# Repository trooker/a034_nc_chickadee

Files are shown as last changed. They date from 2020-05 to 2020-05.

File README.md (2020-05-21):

# a034_nc_chickadee
Ventilator Simulator Platform Synthesized From Published Mechanical Ventilator Design Literature Via FreeCAD Opensource CNC Machine Technology Using Arduino Boards/Shields

See: http://abbottanp.com/ for project engineering details.

While stuck in "lock-down" this project evolved and matured.  

Disclaimer:

1> The project presented here as a lowcost Ventilator Simulator Platform. It is not a qualified medical device at any level. This projects as presented here is not qualifed for any medical application. The project as presented should serve as a test platform and simulator supporting further development of the bio-medical equipment.

2> No warranty is made regarding the servicability or fitness for use of this low cost prototype ventilator. A user may employ, enjoy or engage in this project under the terms of the GNU General Public License (GNU GPL or GPL) as OpenSource software licenses that guarantee end users the freedom to run, study, share, and modify the software. All copyrights privildeges are reserved.

Evolution of Project:

The goal of this project was to gain a layman's level of understanding of the complexity of ventilators. This understanding was to be added to my CommonPlace Book of knowledge. While chasing this pursuit various seacrh strings associated with Forrest Bird led to the referensnces listed further below. The question eventually became one of "can CNC style machines possibly accomplish some level of ventilator fucntionality" using only components currently "on-hand"? Once that has been achieved can the resulting venitlator simulation platform serve a useful purpose as a learnig resource?
Working Assumptions:

Working Assumptions:

    +Ability to read technical material and translate into specification/work-product.
    +Experience creating Arduino project content within Sloeber or similar IDE.
    +Facility to adapt hardware as need to integrate with software to accomplish a task.
    +Implementing a design using only parts that are currently in the project's einventory.

Reference:

++ MIT Student Project: https://web.mit.edu/2.75/projects/DMD_2010_Al_Husseini.pdf

++ Theory of Operation: https://my.clevelandclinic.org/-/scassets/files/org/respiratory/fundamentals-of-mechanical-ventilation.ashx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

++ Excellent Introduction Class: https://www.k-space.org/Class_Info/EE497/KAU_Ventilator_lec.pdf

Status:

1> Project completed to the point where additonal components would need to be purchased and incorporated.  The Arduino program module is functional at the Arduino Base Shield and Stack.  The program drives an X axis piston stepper and two angular motion  AB axes to control inspiration and expiration.  The most minimal breaths per minute for the Tidal Volume (expressed as mL) was demonstrated by the "model".  No air flow was achieved due to the lack of components. 

2> Using FreeCAD the mechanical aspects of the ventilator simulatior prototype platform was generated.  That lead to several evolutions in the approach ot the toolpaths needed for generting a gcode set of statements for integrating a "piston stroke cycle coupled with inspiration and expiration valve control. The proposed gcode soultion was verified at tthe Arduino stack level and under LinuxCNC.  

3> A routine process of converting a test subjects ventilation requirements into the volume and piston stroke length was achieved.  A basic web page input form collects the specification.  That is emailed to a receipent who makes a global repalcement (from "=" to ",") in the specification/data.  That data is then imported to a "canned" spreadsheet that parse the data elements into usable "gcode" content.  Loading that content to a file called "dilni.ngc" allows the "ventilator simulator" to executed cleanly.

4> It served as a great learning tool.

Closing:

Helpful comments are encouraged.  The spelling, grammar, and syntax will improve if the project moves forward from this point.

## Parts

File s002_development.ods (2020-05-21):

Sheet: Development Only
 |  | Given | Calculate |  |  |  | PVC Pipe | PVC Dia IO | Radius | h for Vtt | Cycle Time 1706.7 Steps/Inch | Cycle Time 46.4 Steps/Inch | PVC Pipe 1.5 | Cycle Time 46.4 Steps/Inch | Body Weight Pounds | Tidal Volume VT kg/ml
 | Pounds to Kilograms | 1 | 0.453592 | 0.453592 |  |  | 0.75 | 0.769 | 0.3845 | 17.9 |  |  | 10.0
 |  | 150 | 68.0 |  |  |  | 1 | 1.029 | 0.5145 | 10.0 |  |  | 10.0
 | CubicInch to MiliLiters | 1 | 16.3871 | 16.3871 |  |  | 1.5 | 1.61 | 0.805 | 4.1 | 01:35 | 39.9 | 10.0 |  |  | 2
 |  | 8 | 131.097 |  |  |  | 2 | 2.03 | 1.015 | 2.6 | 01:14 |  | 10.0
 |  |  |  |  |  |  | 2.5 | 2.61 | 1.305 | 1.6 | 01:00 |  | 10.0
 |  |  |  |  |  |  | 3 | 3.03 | 1.515 | 1.2 | 00:55 |  | 10.0
 |  |  |  |  |  |  | 3.5 | 3.6 | 1.8 | 0.8 | 00:50 |  | 10.0
 | pulled from email ==> | Inputs4venti_999 |  |  |  |  | 4 | 4.03 | 2.015 | 0.7 | 00:48 |  | 10.0
From doEmail.html |  | inputs4venti_998.csv |  |  |  |  | 4.5 | 4.6 | 2.3 | 0.5 | 00:45 |  | 10.0
email |  | Pasted as CSV |  |  | Calculation | Copy to Header of dilni.ngc | 5
aname=afgxn nsh | Author’s Name | aname | afgxn nsh |  | afgxn nsh | ;Author: afgxn nsh
amail=nowat@here.com | Author’s Email | amail | nowat@here.com |  | nowat@here.com | ;Author-Email: nowat@here.com
aphone=392-984-9903 | Author’sTelephone | aphone | 392-984-9903 |  | 392-984-9903 | ;Author-Telephone: 392-984-9903
sname=klhhl jupo | Subject’s Name | sname | klhhl jupo |  | klhhl jupo | ;Subject: klhhl jupo
eweight=150 | Weight LBS | eweight | 150 |  |  | ;NOTE: Hello cowboy
mweight= | Weight KG | mweight |  |  | 68.0 | ;Weight kg: 68.0388
stvolume=2 | Tidal Volume mL/kg | stvolume | 2 |  | 136.1 | ;Tidal Volume mL==: 136.0776
comment=Hello cowboy. | Comment: Yes/No | comment | Hello cowboy |  | no
 |  |  |  |  |  | G1 X-4.07889854937866 |  | Vtt In^3
 |  |  |  |  |  |  |  | 8.3039463969

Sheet: Input_Worksheet
 | Given | Calculate
Pounds to Kilograms | 1 | 0.453592
 | 150 | 68.0
CubicInch to MiliLiters | 1 | 16.3871
 | 8 | 131.097
Data pulled from email | Inputs4venti_iii.csv |  |  | 1> Copy data from email to a text file.
From doEmail.html | inputs4venti_998.csv | Example |  | 2> Perform a global replacement of “=” with “,”
Data As Received | aname=afgxn nsh | Name “=” Value |  | 3> Save text file with csv extension.
 |  |  |  | 4> Import csv text file to C13. |  |  |  |  |  |  |  | 150 Pound Body Weight
 |  |  |  |  |  |  |  |  |  |  |  | PVC Pipe 1.5 |  |  | PVC Pipe 1.0 |  |  | PVC Pipe 2.0
Content of Input Email As Received Prior to Converting to CSV | Comment | Object’s Name | Object’s Value |  | Calculation |  | Copy to Header of “dilni.ngc” | PVC Pipe | PVC Dia Interior Inch | Radius | Length of Required Stroke | Tidal Volume ML/kg | Length of Required Stroke |  | Tidal Volume ML/kg | Length of Required Stroke |  | Tidal Volume ML/kg | Length of Required Stroke
aname=afgxn nsh | Author’s Name | aname | afgxn nsh |  | afgxn nsh |  | ;Author: afgxn nsh | 1 | 1.029 | 0.5145 | 10.0 | 2 | 4.1 | * | 2 | 10.0 | ** | 2 | 2.6
amail=nowat@here.com | Author’s Email | amail | nowat@here.com |  | nowat@here.com |  | ;Author-Email: nowat@here.com | 1.5 | 1.61 | 0.805 | 4.1 | 4 | 8.2
aphone=392-984-9903 | Author’s Telephone | aphone | 392-984-9903 |  | 392-984-9903 |  | ;Author-Telephone: 392-984-9903 | 2 | 2.03 | 1.015 | 2.6 | 6 | 12.2
sname=klhhl jupo | Subject’s Name | sname | klhhl jupo |  | klhhl jupo |  | ;Subject: klhhl jupo |  |  |  |  | 8 | 16.3
eweight=150 | Weight LBS | eweight | 150 | lbs |  | na | ;NOTE: Hello cowboy |  |  |  |  | 10 | 20.4 | ** | 10 | 49.9 |  | 10 | 12.8
mweight= | Weight KG | mweight |  | kg | 68.0 | kg | ;Weight kg: 68.0388 |  |  |  |  | 20 | 40.8
stvolume=2 | Tidal Volume mL/kg | stvolume | 2 | mL/kg | 136.1 | mL | ;Tidal Volume mL==: 136.0776 |  |  |  |  | 50 | 102.0
comment=Hello cowboy. | Comment: Yes/No | comment | Hello cowboy |  | no |  |  | Vtt In^3
 |  |  |  |  |  |  | G1 X-4.07889854937866 | 8.3039463969 |  |  |  |  |  |  |  |  | *: 39.9 seconds as tested 200514_1307
 |  |  |  |  |  |  |  |  |  |  |  |  |  |  |  |  | **: 21.8 start + cycle, 16.2 cycle
 |  |  |  |  |  |  |  |  |  |  |  |  |  |  |  |  | ***: Material on-hand.

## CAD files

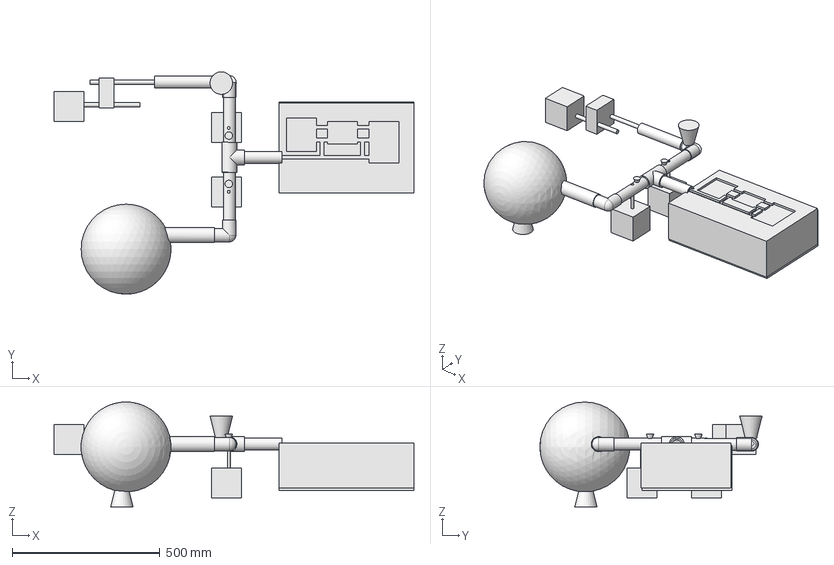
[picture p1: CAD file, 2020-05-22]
037_972_nc_chickadee_3stepper_working.FCStd
1219.2 x 753.0 x 355.1 mm
block
Inspiration001
Exspiration001
Elbow_Cut_Esp
Elbow_Cut_Insp
Vortex
Exspiration
Inspiration
TeeCoupler
ExhaustReservoir+Bleeder
Saddle1
Leadscrew
Stepper1
Piston
Stepper2
ExpPressureCone
InspPressureCone
InspInletValve
Stepper3

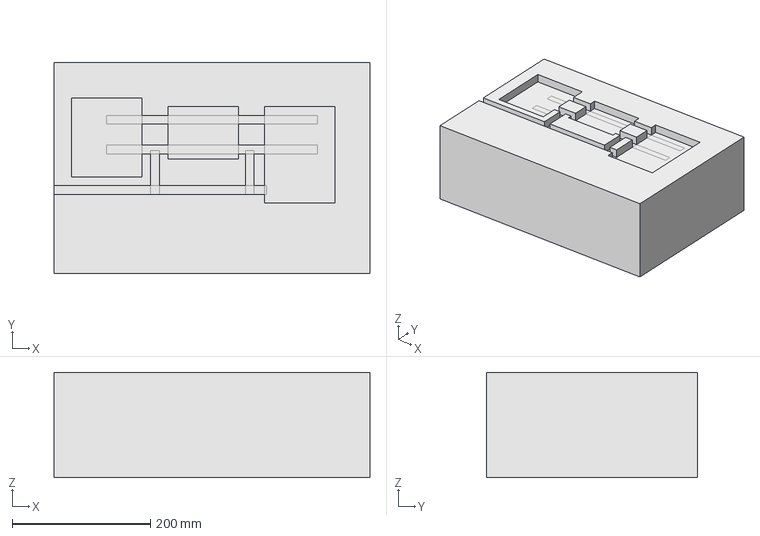
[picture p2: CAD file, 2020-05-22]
036_testLungRespitoryProfile_987.FCStd
457.2 x 304.8 x 152.4 mm

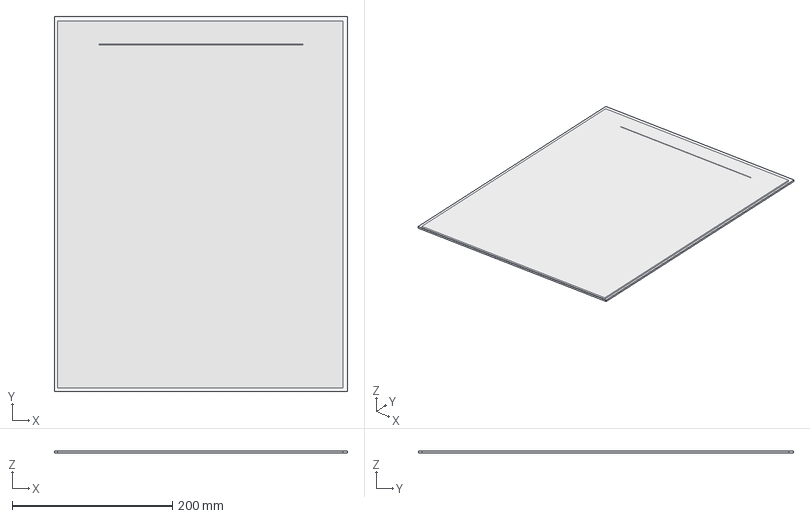
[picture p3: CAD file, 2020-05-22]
037_985_chickadee.FCStd
365.8 x 467.4 x 2.54 mm
WorkPlate_PistonCut
Model-WorkPlate_PistonCut
Model-WorkPlate
Stock

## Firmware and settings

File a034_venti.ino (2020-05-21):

/* Copyright © 1988-2020 by Abbott Analytical Products. All Rights Reserved.
 * 200427_tr seems ot have broken the SD read looping
 *        Everything now hangs at the LCD setup fina 1403 message
 * 200426_tr removed showDisplay stuff
 * 200423_tr upgrade the angular movemnt of stepper A/B ref:
 *        http://linuxcnc.org/docs/html/gcode/g-code.html#gcode:g93-g94-g95
 *        using the lure flipper as a template:
 *        G1 G93 G53 A180.00000 F2
 *        Could also use the G94.  Need to test later.
 *        Physically hooked the Stepper B to AMStop. Still have questions about
 *        stepper A/B pin defs in config.h
 *        Evaluating the use of forcing one instruction per line instead of the
 *        normal gcode string of instructions.
 * 200421_tr have FreeCAD and oxxx subroutines workign at Linuxcnc level for testing
 *        of model.
 *        Need G93, G53, A abd B steppers, o101, o102, o103 hard coded into ngc.
 *        angular movement instead of linear.
 *        need to remove extraneous linear tool movement.  Only th e XY are linear
 * 200405_tr copied from a021_xystepper
 *        verified the upload went well.  Setup Fina 2132 confirmed.
 *        confirmed xy both work working with the shields
 *        SD reading functions.  LED and LCD ok. use dilni.ngc in config.h
 *        for test filename.
 *      ##Discovered a potential issue with SD reading and interrupts causing the
 *        targetFileName to become corrupted.  Need Alarm.
 *
 *
 * 200405_tr_ renamed to suit project from: a021_xystepper_gCodeParser_012.ino
 * 180804_tr started adding a axis, I and J for g02/g03 arch moves.
 * 170421_tr completed rebuild using hte Sloeber  G1 X230 Y300 runs.
 *     G1 X422 Y70 runs steppers
 * 170420 Trying to conver to Sloeber
 *     There is a problem with the input 170420_xy... or output to the log
 * 170419 GtkTerm (ASCII tty_ACM0) 170419_usc18 hangs and awaits firing of
 *        gcode file
 * 170418 GtkTerm and 170418_usc018_eject_logadj.cnc no longer works
 *        Note 170419_*.cnc was built from 170416_log_2158.
 * 170415 Cleanup serial prints and leverge feedrate
 *    Serial Monitor
 *    170414_usc018_eject.cnc line by line
 *    G1 X51.668 Y72.274 F7800.000 => RUns Y okay
 *
 * 170413_work with feedrate, absolute/incremental and units of measure
 *         F, G90/G91, G20/G21
 *         G90;G20; G1 X300 Y100 turns every thing
 *         Corrected for _STEPS_PER_IN/MM
 *         G90; G20; G1 X460 Y10
 * 170411 Added Working on FeedRate
 * 170410 Both XY work to some level via Serial Monitor
 *        G0 X230 Y50
 *        G0 X300 Y5
 *        G0 X-330 Y4
 *          Yeilds
 *          errAdj += difY 275..298
 *                         299, 300
 *             Called backward1()
 *        G0 X500 Y2
 *          errAdj += difY 370, 372,by 2's 400
 *             Called forward1()
 *        G1 X199 Y0
 *        G1 X-195 Y3
 *        Read 002.2_testLine_repeat.cnc from GtkTerm
 *          But no stepper motion
 *        Read boomerangv4_03.cnc from GtkTerm
 *          But no stepper motion
 * 170409 looking at line() function of parse_cmdln
 * 170402_merge GCodeCNCDemo2 with Adafruit Motor shield
 *     drop extraneous controllers
 *     works with G00 code from Serial Monitor command line.
 *   1> Used GtkTerm and boomeragn.cnc to drive steppers
 *   2> GtkTerm copy/paste of r004_002_testLine runlog to drive
 *   3> raw file GtkTerm + 002_testLine_repeast.nc
 *   4> raw file GtkTerm ...
 *
 *
 *
 * 170330
 *
 * https://github.com/MarginallyClever/GcodeCNCDemo/wiki
 * https://github.com/MarginallyClever/GcodeSender
 */


#include "a034_config.h"

//------------------------------------------------------------------------------
// GLOBALS
//------------------------------------------------------------------------------

//int   sofar;            // how much is in the buffer
int copyMax = 1;
int copyKnt = 0;



// settings

//From GCodeParser
//#define COMMAND_SIZE 128
char commands[COMMAND_SIZE];
byte serial_count;
int no_serialData = 0;        // attempts to read Serial port
bool comment = false;



//------------------------------------------------------------------------------
// METHODS
//------------------------------------------------------------------------------


//170701_tr
rgb_lcd lcd;

int cnt = 0;
const int LED    = 2;       // the Grove port No. you attached an LED to


String readString = "";
int ledState = LOW;             // ledState used to set the LED
long previousMillis = 0;        // will store last time LED was updated
// the follow variables is a long because the time, measured in miliseconds,
// will quickly become a bigger number than can be stored in an int.
long interval = 1000;           // interval at which to blink (milliseconds)
int doneFlag = -1;              // think tristate
int kntr = 0;                   // loop counter
int loopknt = 0;         // count loop cycles
bool loopdebug = true;  //false;   // controls serial printing of debug info:  true is doit
int workknt = 0;         // count cycle through work
int wait4loop = 10000;
int endOn = wait4loop;         // 200;         // end work loop after
int closeLoopOn = wait4loop;   // end arduino looping after 200 cycles
// Define the delay for the "breathing" effect; change this
// to a smaller value for a faster effect, larger for slower.
const int BREATH_DELAY = 5; // milliseconds



int buzz1Knt = 1;        //
int buzz2Knt = 1;        //
int buzz3Knt = 1;        //siren
int buzzOff  = 2;

const int sigId_led    = 3;     //Port 3 LED   OUTPUT
const int sigId_btn    = 6;     //Port 7 btn   INPUT
const int sigId_buz    = 5;     //Port 6 buzzer OUTPUT


/*
 * wrting a string for trouble shooting loop issues
 */

void loopPrn(String msg)
{
	if (loopdebug == true)
	{
		Serial.println(msg);
	}
}



/**
 * write a string followed by a float to the serial line.  Convenient for debugging.
 * @input code the string.
 * @input val the float.
 */
void foutput(const char *code,float val)
{
 if (isReadyFlag == true)
 {
  Serial.print(code);
  Serial.print(".....");  // my test ln
  Serial.println(val,4);
 }
}


/**
 * print the current position, feedrate, and absolute mode.
 */
void where()
{
  foutput("popped from where() of venit.ino", BADNbr);
  foutput("kntX",kntX);
  foutput("kntY",kntY);
  foutput("Distance along X Axis",kntX / x_steps2in );
  foutput("Distance along Y Axis",kntY / y_steps2in);
  foutput("x units", x_steps2in);
  foutput("y units", y_steps2in);
  foutput("a units", a_steps2deg);
  foutput("b units", b_steps2deg);
  foutput("Current_LocX",current_loc.x);
  foutput("Current_LocY",current_loc.y);
  foutput("Current_LocA",current_loc.a);
  foutput("Current_LocB",current_loc.b);


  foutput("Last fp.X requested via gCode ",fp.x);
  foutput("Last fp.Y requested via gCode ",fp.y);
  foutput("Last fp.a requested via gCode ",fp.a);
  foutput("Last fp.b requested via gCode ",fp.b);

  foutput("F",feedrate);
  foutput("E", extrude);
  foutput("abs_mode ",abs_mode);
}

void help()
{
	//Serial.println("Need help with Flash memory F thingie");
	  Serial.print(F("GcodeCNCDemo2AxisV1 Help: "));
	  Serial.println(VERSION);
	  Serial.println(F("Unit of Measure is in Inches for Linear and Degrees for Angular"));
	  Serial.println(F("Commands:  Used by dilningc"));
	  Serial.println(F("G00 [X(steps)] [Y(steps)] [E(extrude)] [F(feedrate)]; ==> Linear"));
	  Serial.println(F("G01 [X(steps)] [Y(steps)]  [E(extrude)] [F(feedrate)]; ==> Linear"));
	  Serial.println(F("G01 G93 G53 [A(degs)]  [B(degs)][F(feedrate)]; ==> Angular"));
	  Serial.println(F("G20 Set units to inches"));
	  Serial.println(F("G04 P[seconds]; ==> delay"));
	  Serial.println(F("G90; absolute mode"));
	  Serial.println(F("G93; Angular movement of StepperA/B"));
	  Serial.println(F("G53; Machine Coordinate System. Ignored"));
	  Serial.println(F("M02; End of Program"));
	  Serial.println(F("M18; - disable motors"));
	  Serial.println(F("M100; - this help message"));
	  Serial.println(F("M114; - report position and feedrate"));
	  Serial.println(F("All commands must end with a newline."));

//	  Serial.println(F("-G02 [X(steps)] [Y(steps)] [I(steps)] [J(steps)] [E(extrude)] [F(feedrate)]; ==> clockwise arc"));
//	  Serial.println(F("-G03 [X(steps)] [Y(steps)] [I(steps)] [J(steps)] [E(extrude)] [F(feedrate)]; ==> counter-clockwise arc"));
//	  Serial.println(F("-G21 Set units to mm"));
//	  Serial.println(F("-G91; - relative mode"));
//	  Serial.println(F("-G92 [X(steps)] [Y(steps)]; - change logical position"));
//	  Serial.println(F("-M05; - Stop spindle"));

}


/**
 * prepares the input buffer to receive a new message and tells the serial connected device it is ready for more.
 */
void ready_USBinputs()
{
//  sofar=0;  // clear input buffer
  Serial.print(F(">"));  // signal ready to receive input
}

void mgtCmdLn(char c)
{
	    no_serialData = 0;
	    //newlines are ends of commands.
	    if (c != '\n')
	    {
	      if(c==0x18)
	      {
	        Serial.println("Grbl 1.0");
	      }
	      else
	      {
             if ((c == ';')or (c == '('))
	         {comment = true;}
	         // If we're not in comment mode, add it to our array.
	         if (!comment)
	         {
	           commands[serial_count] = c;
	           serial_count++;
	         }
	         if (c == ')')
	         { comment = false; }// End of comment - start listening again
	       } //
	    }
	 //}
      else
	  {
	    no_serialData++;
	    delayMicroseconds(100);


foutput("serial_count....: ", serial_count);


	  //if theres a pause or we got a real command, do it
	  if (serial_count && ((c == '\n'  || (c == 0x0A) ) || no_serialData > 100))
	  {
	    //process our command!
	    Serial.print("ln 2 cmd..: ");
	    Serial.println(commands);
	    showInstruction();
	    parse_cmdln(commands, serial_count);
	    //clear command.
	    init_parse_cmdln();
	  }
	  }
	  }	   //mgtCmdLn()


int do_serial_read()
{
	  char c;
	  bool readchar = false;
	  //read in characters if we got them.
	  if (Serial.available() > 0)
	  {
	    c = Serial.read();
        mgtCmdLn(c);
        return 999;
      }
	  return 1;
}

void  allstop()
{
   digitalWrite((sigId_led+0),LOW);   //LED
   digitalWrite((sigId_btn+0),HIGH);  //btn
   digitalWrite((sigId_buz+0),LOW);   //buzzer
}

void breatherLED()
{
    for(int i=0; i<256; i++)
    {
        analogWrite((sigId_led+0), i);
        delay(BREATH_DELAY);
    }
    delay(100);

}

bool checkBtn()
{
 if (digitalRead(sigId_btn)==HIGH)
  {
     lcd.setCursor(0, 0);
     readString = "Button Pressed";
     showDisplayDebug(readString);
     lcd.setCursor(0, 1);
     readString = "Buzz On LED Off";
     showDisplayDebug(readString);
     digitalWrite((sigId_btn+0),HIGH);
     digitalWrite((sigId_led+0),LOW);
 soundBuzz3(); //siren
     return true;
  } //ifpressed
  else
  {
	  digitalWrite((sigId_btn+0),LOW);
	  digitalWrite((sigId_led+0),HIGH);
	  digitalWrite((sigId_buz+0),LOW);
	  return false;

  }
}



void setupCommo()
{
	  doneFlag = 0;
	  ready_file4reading();
	  ready_USBinputs(); // ready to pass USB Serial traffic  to loop()
	  show2Reset();
}




void dowork()
{
	  //loop_parser();
//   for(;;)
   {
//	if (!checkBtn())
	   {
//		   setupCommo();
//		   break;
	   }
  breatherLED();
	setupCommo();
   if (sderrFlg == 0)
   {//sd active
  	showDisplay("SD Read Repeater");

	  //ready_file4reading();

      loop_sdread();

//foutput("sderrFlg....: ", sderrFlg) ;
//foutput("no_serialData reset..:",  0);
//foutput("getEndOfFileStatus()", getEndOfIleStatus());
      no_serialData = 0;  //reset to look for serial inputs
   }
   else
   {
  	// while ( copyKnt < copyMax)
//foutput("sderrFlg....: ", sderrFlg) ;
//foutput("no_serialData reset..:",  0);
//foutput("getEndOfFileStatus()", getEndOfIleStatus());
//foutput("try serial input...: ", 876);
soundBuzz4(); //siren
  	 switch(do_serial_read())
  	  {
  	  case 1: no_serialData++;
  	  break;
  	  case 999: no_serialData = 0;  //reset to read next serial input
  	  break;
  	  } // end do_serial_read check
   }
   } // end infinite loop
   foutput("do_work....", 3838);

}


void setup()
{
	  Serial.begin(BAUD);  // open coms
	  Serial.println("Serial is running");

	  help();  // say hello
	  pinMode((sigId_led+0),INPUT);    //LED   _
	  pinMode((sigId_btn+0),INPUT);    //btn
	  pinMode((sigId_buz+0),OUTPUT);   //buzzer
	  allstop();

	  setup_controller();  //ams1
      set_position(0,0,0,0,0);  // set staring position
	 //init_steppers does this feedrate((MAX_FEEDRATE + MIN_FEEDRATE)/2);  // set default speed

 	  init_parse_cmdln(); //process string
	  init_steppers();   //ams1
	  setup_sd();
      setupCommo();
      showSetup();  //fires LCD message


}


// The loop function is called in an endless loop
void loop()
{

	if (buzz1Knt < buzzOff) //play tune once
	{
		soundBuzz1(); //happy birthday
	    buzz1Knt++;
	}

	dowork();
	  //no data?  turn off steppers
	 foutput("no-data...SD..: ",no_serialData);
	 foutput("no serial.....: ",copyKnt);


if (buzz2Knt < buzzOff)
	    {
	 	   soundBuzz2(); //shave haircut
	       buzz2Knt++;
	    }



	if ((no_serialData > closeLoopOn) || (loopknt >= closeLoopOn))
	  {
	    disable();
	    showDone();
	    Serial.println("disable");
	    if (buzz2Knt < buzzOff)
	    {
	 	   soundBuzz2(); //shave haircut
	       buzz2Knt++;
	    }
	    allstop();

	  }
	else
	{
	    showMills();
	}
}

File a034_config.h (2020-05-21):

#ifndef A034_CONFIG_H_
#define A034_CONFIG_H_


/*Copyright © 1988-2020 by Abbott Analytical Products. All Rights Reserved.
 * NC_Chickadee
 * Header file used to centralize libraries used by project
 * 200518_tr testing continues;
 *           1> A cycle is now down to 16.1 second.  Cycle
 *           defined as a start when the SD reads the dilni.ngc and then cycles
 *           to the next load/read of the file.
 *           2> It appears that the serial messages can be clipped a bit.
 *           3> StepperB/A do not seem to be zero/starting at the same
 *           location each cycle. The home-ing sequence needs to be set for
 *           true zero:  Specifically==
 *                                     G00 B0
 *                                     G00 G53 X0 Y0 A0
 * 200514_testing begins.
 *           X-4.1 ==> 39.9 second respiratory cycle + loading + machine zero.
 *                     Tidal Volume ==>
 *           X-10  ==> 42.5 seconds
 *           Need to look at the StepperB/A speeds and the Zero actions.
 *           removed bad note on calculation of step per inch.
 *           Changed to making one step() pass using steps4_90rotate, 400 rpm,
 *           and step_Methiod INTERLEAVE
 *           X-10 ==> 26.6 start: zero, sd, cycle, close
 *                ==> 20.7 sd, cycle, close red to red
 *           Cut extraneous dev comments from dilin.ngc
 *           X-10 ==> 21.8 start: zero, sd, cycle, close
 *                ==> 16.2 sd, cycle, close red to red
 *
 * 200511_tr reworked the Steps Per Inch.  Need to test new number.
 * 205009_tr take a look at movepiston() from onestep to steps
 *           using step_method DOUBLE
 * 200505_tr added DEBUG1 to control dev msg
 * 200504_tr changed the x/y/z_steps2in to steps2in
 * 200430_tr corrected the defaulting to mm instead of inches
 *           float x_steps2in = X_STEPS_PER_INCH;  //X_STEPS_PER_MM;
 * 200428_tr corrected Apirpac stepper steps/degree per mfg spec
 *           -incorporate LinuxCNC simulator *.ini
 *                stepgen chickadee              nexgen_09_venti
 *            X   MIN_LIMIT = -2  inch         MIN_LIMIT = -2  inch
 *                MAX_LIMIT = 20               MAX_LIMIT = 20
 *            Y   MIN_LIMIT = -2  inch         MIN_LIMIT = -2.5
 *                MAX_LIMIT = 20               MAX_LIMIT = 22
 *            A,B MIN_LIMIT = 0.0  degree      MIN_LIMIT = -36000.0 default  degree
 *                MAX_LIMIT = 90.0             MAX_LIMIT =  36000.0default  degree
 *
 *
 * 200426_tr  added block on I2C pinouts for various arduinos
 * 200425_tr  added adafruit pdf for v2.3
 *            https://cdn-learn.adafruit.com/downloads/pdf/adafruit-motor-shield-v2-for-arduino.pdf
 *            Reviewed the MarginallyClever aagain and downloaded current cloe from
 *            github.  Liked the usage of strutcure for the motors.
 * 200422_tr  added extern makeline(), support for Stepper B without dropping Z
 */
//------------------------------------------------------------------------------
// 2 Axis CNC Demo
// dan@marginallycelver.com 2013-08-30
//------------------------------------------------------------------------------
// Copyright at end of file.
// please see http://www.github.com/MarginallyClever/GcodeCNCDemo for more information.
//
/* 200405_tr renamed test.cnc to respitory.ngc as the targetFile
 *
 */

//------------------------------------------------------------------------------
// CONSTANTS
//------------------------------------------------------------------------------
// supported control boards
//#define DEBUG1

#define AMS1 (1)
#define AMS2 (2)

#include "Arduino.h"
#include <Wire.h>
#include <Adafruit_MotorShield.h>
//#include <AccelStepper.h>
#include <SPI.h>
#include <SD.h>
#include "rgb_lcd.h"




// change this line to select a different control board for your CNC.
#define CONTROLLER AMS1

//#define DEBUG1  //verbose

/* Machine Parameters*/
// define the parameters of our machine.

/* Radioshack 2730767  5wire 1:64  5vdc
 * kiatronics 28byj-48 5v
float X_STEPS_PER_INCH = 30.72;
float X_STEPS_PER_MM = 1.2094 //this is wrong 25.6;  //????
float STEP_PER_DEG = 11.25   //https://lastminuteengineers.com/28byj48-stepper-motor-arduino-tutorial
float STEP_PER_REV = 2038  // with internal gearing11/
int X_MOTOR_STEPS   = 64;  //  5.625 degree per step

*/

/* HP J45D52HT
float Y_STEPS_PER_INCH = 96;
float Y_STEPS_PER_MM  =  3.779527559  //is wrong  80;
int Y_MOTOR_STEPS   = 200;  //  1.8 degree per step
*/


//Navaho windstrument
String targetFileName = "dilni.ngc";
bool isReadyFlag = false;      // turns-off.on the foutput() after reading G20
bool isMachZeroFlag = false;  // false until machine completes zero opn
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

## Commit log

2020-05-21 Added Engineering Deveoplment Spreadsheets
    s001_*.ods captures early what-iffing of physical piston. s002_*.ods documents a fine tuning of the physical design.
    [s001_early_crunch.ods, s002_development.ods]
2020-05-22 FreeCAD project files and gcode test files
    Three FreeCAD development files: Test Lung, Chickadee Ventilator Model, and Chickadee Workplate
    Two gcode test files. They are similar except for changes made to accommodate testing under LinuxCNC.
    [036_testLungRespitoryProfile_987.FCStd, 037_972_nc_chickadee_3stepper_working.FCStd, 037_985_chickadee.FCStd]

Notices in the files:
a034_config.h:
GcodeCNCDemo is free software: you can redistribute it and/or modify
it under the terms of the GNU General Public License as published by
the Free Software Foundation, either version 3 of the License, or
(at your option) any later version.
